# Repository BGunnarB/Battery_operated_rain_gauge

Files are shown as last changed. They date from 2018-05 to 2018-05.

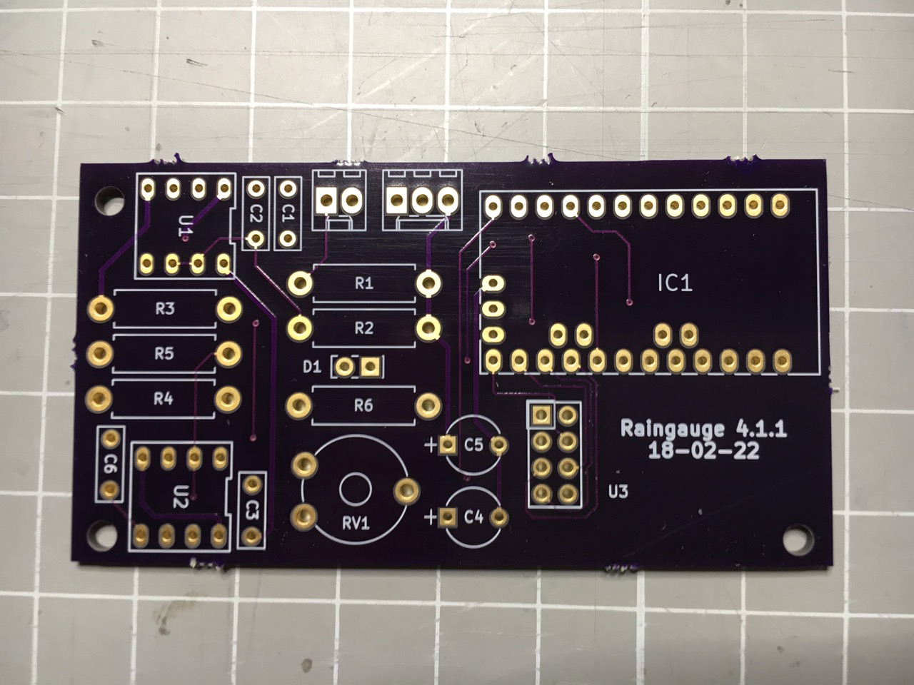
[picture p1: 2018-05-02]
IMG_0528.jpg

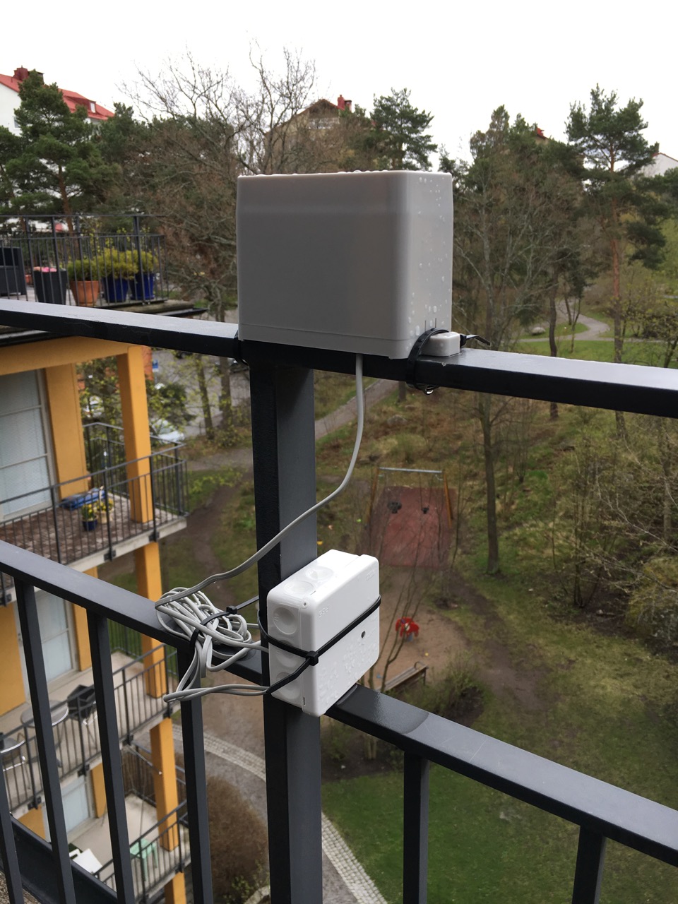
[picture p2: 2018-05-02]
IMG_0531.jpg

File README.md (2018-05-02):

# Battery_operated_rain_gauge

This project is for a battery-operated (2 x AA) rain-gauge using the MySensors library.

The requirements were that the gauge should report the rainfall during the last 5 to 10 minutes to the controller. Since the node should be asleep most of the time it would not be able to keep track of the time between reports, so some other way of time-keeping should be provided.

Also, the tipping-bucket rain-gauge typically generated contact bounce, which has to be filtered out.

The solution is based on an Arduino Pro-Mini 8 MHz, 3.3 V and the NRF24L01+ radio. Timing is provided by a CMOS 555 timer which generates one pulse every minute. Every minute-pulse generates an interrupt. After a pre-set number of minute pulses, the rainfall and battery status are reported. 

Every time the bucket tips, an interrupt is generated. The rainfall is incremented by the amount that the bucket indicates. The calibration factor is set in the sketch. The contact bounce is filtered out by another CMOS 555 timer since I had a few of these handy rather than messing around with software filtering, which may disrupt the interrupt service routine.

To indicate that the timer generated an interrupt, a LED flashes green. To indicate that the rain-bucket generated an interrupt, the LED flashes red.

The battery sensor circuit is off the pcb but is the usual voltage divider 1M in series with 470k found elsewhere on the MySensors webpage. A capacitor of 100 nF is added across the 470k resistor for decoupling of noise.

It is up to the controller (in my case OpenHAB) to sum up the rainfall during e.g. 24 hours. The rain-gauge simply reports the rainfall during the elapsed period.

The total power consumption by the circuit is 240 nA when sleeping. The LED on the Arduino has been removed but not the power regulator.

The PCB was designed in KiCad and the board produced by OSHPark in the US.

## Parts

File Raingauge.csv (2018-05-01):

Id | Designator | Package | Quantity | Designation | Supplier and ref
1 | C1,C2,C3 | C_Rect_L7.2mm_W2.5mm_P5.00mm_FKS2_FKP2_MKS2_MKP2 | 3 | 100n
2 | C4,C5 | CP_Radial_Tantal_D5.5mm_P5.00mm | 2 | 22u
3 | C6 | C_Rect_L7.2mm_W2.5mm_P5.00mm_FKS2_FKP2_MKS2_MKP2 | 1 | 10n
4 | D1 | LED_Rectangular_W5.0mm_H2.0mm | 1 | LED_Dual_2pin
5 | R1 | R_Axial_DIN0411_L9.9mm_D3.6mm_P12.70mm_Horizontal | 1 | 33k
6 | R2,R4 | R_Axial_DIN0411_L9.9mm_D3.6mm_P12.70mm_Horizontal | 2 | 1M
7 | R3 | R_Axial_DIN0411_L9.9mm_D3.6mm_P12.70mm_Horizontal | 1 | 2.5M
8 | R5 | R_Axial_DIN0411_L9.9mm_D3.6mm_P12.70mm_Horizontal | 1 | 22k
9 | R6 | R_Axial_DIN0411_L9.9mm_D3.6mm_P12.70mm_Horizontal | 1 | 56
10 | RV1 | Potentiometer_Trimmer_Piher_PT-10v10_Horizontal_Px10.0mm_Py5.0mm | 1 | 1M
11 | U1,U2 | DIP-8_0_ELL | 2 | LMC555xN
12 | U3 | NRF24L01 | 1 | NRF24L01
13 | IC1 | pro_mini | 1 | ArduinoProMini
14 | J2 | Molex_KK-6410-03_03x2.54mm_Straight | 1 | Battery
15 | J1 | Molex_KK-6410-02_02x2.54mm_Straight | 1 | Bucket

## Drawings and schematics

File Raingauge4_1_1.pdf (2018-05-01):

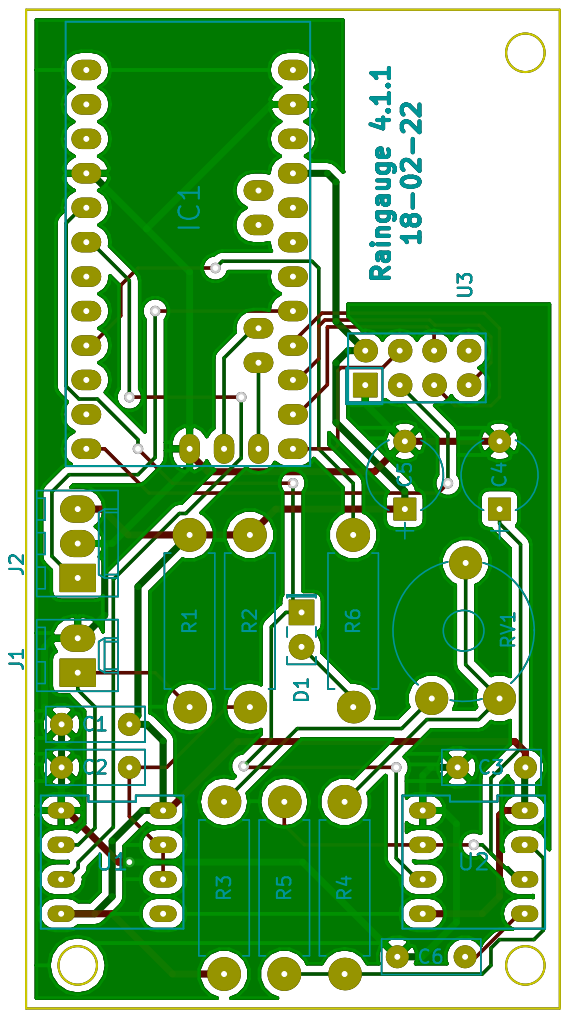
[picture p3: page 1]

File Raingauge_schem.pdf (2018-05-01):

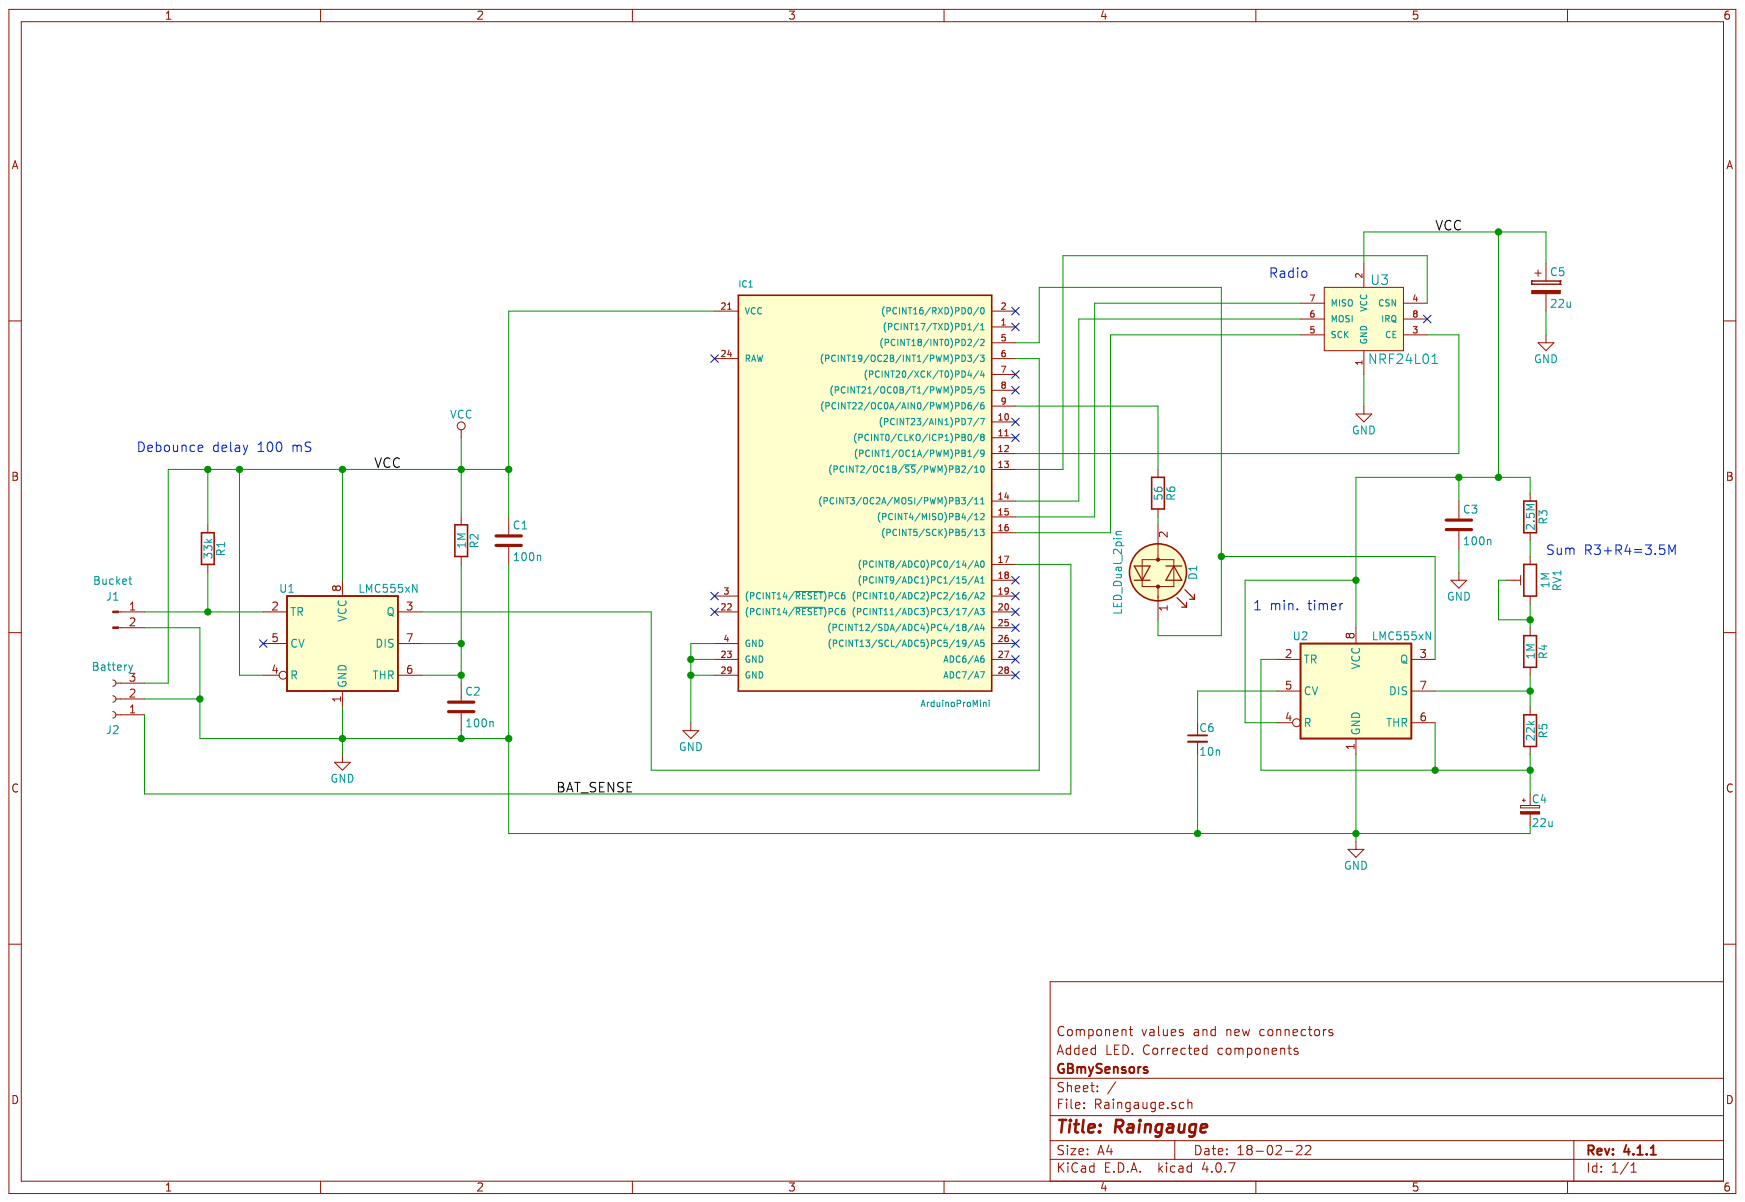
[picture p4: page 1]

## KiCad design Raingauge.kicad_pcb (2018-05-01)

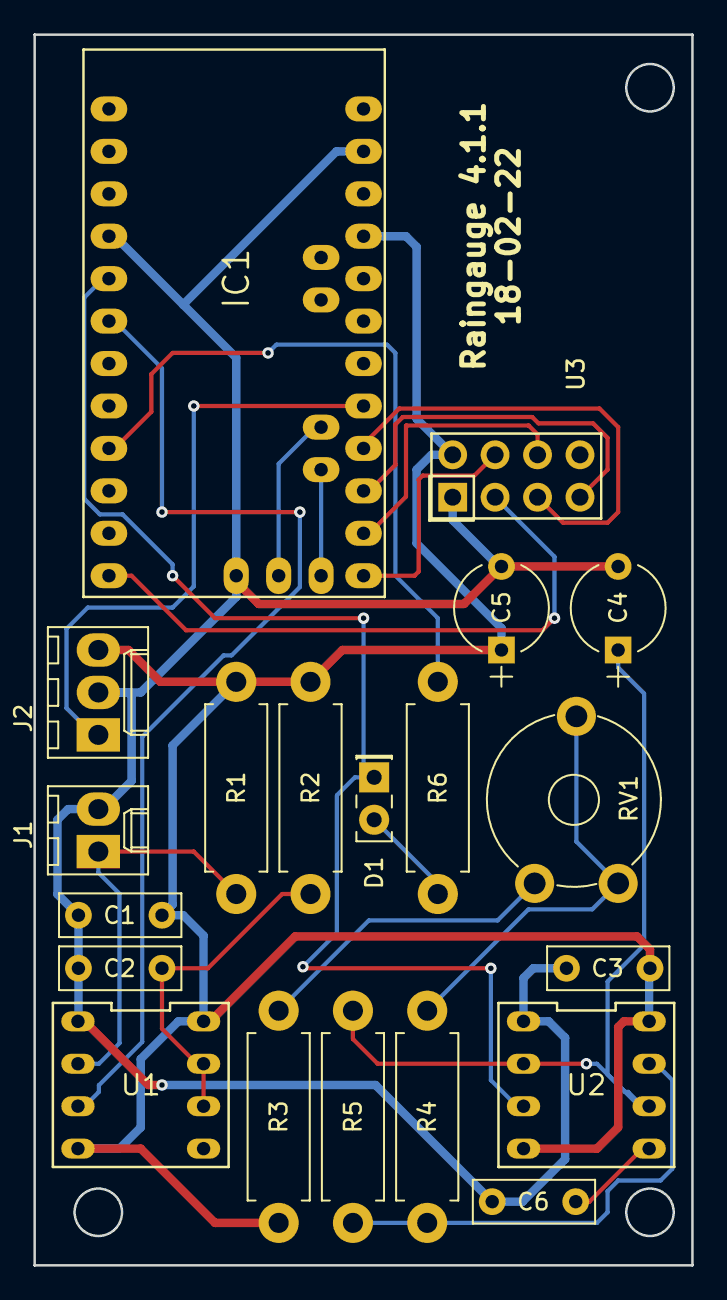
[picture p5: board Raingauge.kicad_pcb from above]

Board: 2 copper layers, 39.4 x 73.7 mm, 20 parts (0 on the bottom side), 19 nets.

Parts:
C1, C2, C3: 100n; C_Rect_L7.2mm_W2.5mm_P5.00mm_FKS2_FKP2_MKS2_MKP2
C4, C5: 22u; CP_Radial_Tantal_D5.5mm_P5.00mm
C6: 10n; C_Rect_L7.2mm_W2.5mm_P5.00mm_FKS2_FKP2_MKS2_MKP2
D1: LED_Dual_2pin; LED_Rectangular_W5.0mm_H2.0mm
IC1: ArduinoProMini; pro_mini
J1: Bucket; Molex_KK-6410-02_02x2.54mm_Straight
J2: Battery; Molex_KK-6410-03_03x2.54mm_Straight
R1: 33k; R_Axial_DIN0411_L9.9mm_D3.6mm_P12.70mm_Horizontal
R2, R4: 1M; R_Axial_DIN0411_L9.9mm_D3.6mm_P12.70mm_Horizontal
R3: 2.5M; R_Axial_DIN0411_L9.9mm_D3.6mm_P12.70mm_Horizontal
R5: 22k; R_Axial_DIN0411_L9.9mm_D3.6mm_P12.70mm_Horizontal
R6: 56; R_Axial_DIN0411_L9.9mm_D3.6mm_P12.70mm_Horizontal
RV1: 1M; Potentiometer_Trimmer_Piher_PT-10v10_Horizontal_Px10.0mm_Py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
U1, U2: LMC555xN; DIP-8_0_ELL
U3: NRF24L01

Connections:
/BAT_SENSE: IC1.17, J2.1
GND: C1.2, C2.2, C3.2, C4.2, C5.2, C6.2, IC1.4, IC1.23, IC1.29, J1.2, J2.2, U1.1, U2.1, U3.1
unnamed: C2.1, R2.2, U1.6, U1.7
unnamed: C4.1, R5.2, U2.2, U2.6
unnamed: C6.1, U2.5
unnamed: D1.1, IC1.5, U2.3
unnamed: D1.2, R6.2
unnamed: IC1.6, U1.3
unnamed: IC1.9, R6.1
unnamed: IC1.12, U3.3
unnamed: IC1.13, U3.4
unnamed: IC1.14, U3.6
unnamed: IC1.15, U3.7
unnamed: IC1.16, U3.5
unnamed: J1.1, R1.2, U1.2
unnamed: R3.2, RV1.3
unnamed: R4.1, RV1.1, RV1.2
unnamed: R4.2, R5.1, U2.7
VCC: C1.1, C3.1, C5.1, IC1.21, J2.3, R1.1, R2.1, R3.1, U1.4, U1.8, U2.4, U2.8, U3.2

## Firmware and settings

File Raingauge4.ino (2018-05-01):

/*
 Arduino Tipping Bucket Rain Gauge
 2018-02-15
 
 Arduino Tipping Bucket Rain Gauge
 Utilizing a tipping bucket sensor, your home automation controller and the MySensors.org
 gateway you can measure and sense local rain.  This sketch transmits the rain accumulated
 every SENDPERIOD minutes. Any aggregation, statistics etc. will be done by the controller.
 
 
 
 * Should run on any Arduino
 * Adapted for battery operation
 
 by @bgunnarb for free public use
 
 Change Log
 4.0   First version
 4.1   Introduced dual color LED for bucket tip and timing pulse.
 4.1.1 Corrected battery measurement 
 */

//#define MY_DEBUG // Enable MySensors debug prints to serial monitor

// Enable and select radio type attached
#define MY_RADIO_NRF24
//#define MY_RADIO_RFM69

//#define MY_RF24_PA_LEVEL RF24_PA_MAX //Options: RF24_PA_MIN, RF24_PA_LOW, RF24_PA_HIGH, RF24_PA_MAX

#define MY_NODE_ID 43  //uncomment this line to assign a static ID

// #include <math.h>
#include <MySensors.h>

#define SKETCH_NAME "Rain Gauge  18-02-20"
#define SKETCH_VERSION "4.1.1"

#define DWELL_TIME 40  // this allows for radio to come back to power after a transmission, ideally 0 

#define DEBUG_ON  // Rain gauge specific debug messages. 


#define TIP_SENSOR_PIN 3 // Pin the tipping bucket is connected to. Causes interrupt 1
#define TIMER_PIN 2   // Causes interrupt 0
#define LED_PIN 6
#define CALIBRATE_FACTOR 35 // amount of rain per rain bucket tip e.g. 5 is .05mm
#define SENDPERIOD 5  // number of external timer interrupts before sending data to controller


#define CHILD_ID_RAIN_LOG 1  // Keeps track of rainfall

#ifdef  DEBUG_ON
  #define DEBUG_PRINT(x)   Serial.print(x)
  #define DEBUG_PRINTLN(x) Serial.println(x)
  #define SERIAL_START(x)  Serial.begin(x)
  #else
  #define DEBUG_PRINT(x)
  #define DEBUG_PRINTLN(x)
  #define SERIAL_START(x)
#endif

#define BATTERY_SENSE_PIN A0  // Input pin for battery sense
#define VMIN 1.0  // (Min input voltage to regulator according to datasheet or guessing. (?) )
#define VMAX 3.22 // (Known or desired voltage of full batteries. If not, set to Vlim.)
#define BLINK_TIME 500 // Time the LED is lit in mS
//
volatile unsigned int rainBucket=0;
uint8_t whoInterrupted = 2;  // What caused the interrupt? 0 = external timer, 1 = Bucket tipped
uint8_t periodCounter = 0;  // Number of timer interrupts counted


MyMessage msgRain(CHILD_ID_RAIN_LOG, V_RAIN);
//
//
void presentation()  {
  // Register the sensor to gw (it will be created as child device)
  sendSketchInfo(SKETCH_NAME, SKETCH_VERSION);
  wait(DWELL_TIME);
  present(CHILD_ID_RAIN_LOG, S_RAIN);

  DEBUG_PRINTLN(F("Sensor Presentation Complete"));
}

void before()
{
  // use the 1.1 V internal reference
  #if defined(__AVR_ATmega2560__)
    analogReference(INTERNAL1V1);
  #else
    analogReference(INTERNAL);
  #endif
  
}
void setup()
{
  #ifndef MY_DEBUG
  SERIAL_START(115200);  //Start serial if MySensors debugging isn't enabled
  #endif
  //
  // Set up the IO
  pinMode(TIP_SENSOR_PIN, INPUT);
  pinMode(TIMER_PIN, INPUT);
  pinMode(LED_PIN, OUTPUT);
  digitalWrite(LED_PIN, HIGH); 
  digitalWrite(LED_PIN, LOW); // Low indicates that bucket has tipped. This is just for test at setup.
  wait(BLINK_TIME);
  digitalWrite(LED_PIN, HIGH);
  
}

void loop()
{
  
  whoInterrupted = sleep(TIMER_PIN - 2, FALLING, TIP_SENSOR_PIN - 2, RISING, 0);
  DEBUG_PRINTLN(whoInterrupted);
  if (whoInterrupted == 0) {
    sendRain();
  }
  if (whoInterrupted == 1) {
    incrementRain();
  }
  
}
   
void sendRain() {   
  DEBUG_PRINTLN(F("One period started."));
  periodCounter++;

  if (periodCounter >= SENDPERIOD) {
     send(msgRain.set((float)rainBucket / 100., 1));
     DEBUG_PRINTLN(F("SENDPERIOD elapsed."));
     DEBUG_PRINTLN(rainBucket);
     // get the battery voltage
     int sensorValue = analogRead(BATTERY_SENSE_PIN);    // Battery monitoring reading
     float Vbat  = sensorValue * 0.003363;
     int batteryPcnt = static_cast<int>(((Vbat-VMIN)/(VMAX-VMIN))*100.);   
     sendBatteryLevel(batteryPcnt);  
     DEBUG_PRINTLN(F("Battery Percent:"));
     DEBUG_PRINTLN(batteryPcnt);
     rainBucket = 0;
     periodCounter = 0;
  
  }
}
   
void incrementRain() {
  DEBUG_PRINTLN(F("Bucket tipped."));
  rainBucket += CALIBRATE_FACTOR; // adds CALIBRATE_FACTOR hundredths of unit each tip
  digitalWrite(LED_PIN, LOW);
  delayMicroseconds(BLINK_TIME * 20);
  digitalWrite(LED_PIN, HIGH);
  
}
//

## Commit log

2018-05-01 First project description
    First commit
    [Raingauge.kicad_pcb, Raingauge.sch]
2018-05-01 Edits and more files
    Edited README.MD and added the Arduino sketch.
2018-05-01 Added image of pcb
2018-05-01 Added BOM
    [Raingauge.csv]
2018-05-03 Added Gerber files
    [Raingauge-B.Cu.gbr, Raingauge-B.Mask.gbr, Raingauge-B.SilkS.gbr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]
